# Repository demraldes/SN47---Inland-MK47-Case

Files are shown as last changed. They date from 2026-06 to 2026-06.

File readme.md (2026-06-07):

# Sneed's Inland MK47 Case

The Sneed SN47 is a retro-styled 3D-printed case for the Inland MK47, inspired by vintage Cherry and IBM keyboards. It is directly compatible with the MK47 plate and PCB assembly and reuses the original self-tapping mounting screws.

The latest version of the case adds 2.5 mm of height above the plate. This should better conceal switches and allow the bottom edge of the keycaps to sit more flush to, or slightly below, the top surface. This revision has not been physically tested, so use it at your own risk. No interference or fitment issues are expected.

## Case Files

For best results, the case should be FDM printed as separate top and bottom halves.

[Case files](https://github.com/demraldes/SN47---Inland-MK47-Case/tree/main/case) are located in this repository. A separate collection of [individual parts](https://github.com/demraldes/SN47---Inland-MK47-Case/tree/main/case/separated%20parts) is also included for duo-tone accents or bottom lettering. For these versions, load the components for each half as a single multi-part object.

## Bill of Materials and Assembly
### BOM

| Part | Spec | Qty | Note |
| --- | --- | --- | --- |
| Case screws | M2-0.4x5 mm | 5 | *Flat head recommended. Socket-head screws may clear the PCB, but this has not been tested.* |
| Heat-set inserts | M2x4x3.2 mm | 5 | |
| Case weights (optional) | 1/4 oz low profile | 14 | *16 mm × 19 mm × 3 mm; CK Auto PN# CKsafeAWW005Black01* |
| Plate screws | *See note* | 6 | *Reuse from MK47* |
| Feet/bumpons | 8 mm diameter | 4 | *Self-adhesive cabinet/furniture bumper pads* |

### Assembly

> The plate screws may not feel like they are well-threaded in the mounting bosses. If necessary, a small amount of PTFE tape can help tighten particularly loose screws, though in testing it has not been an issue.

1. Install the M2 heat-set inserts into the pilot holes in the bottom half of the case. The inserts should sit flush with or slightly below the mating surface.

2. If using weights, place them in the rectangular recesses in the bottom half. Adhering them in place is recommended to prevent shifting or rattling during use.
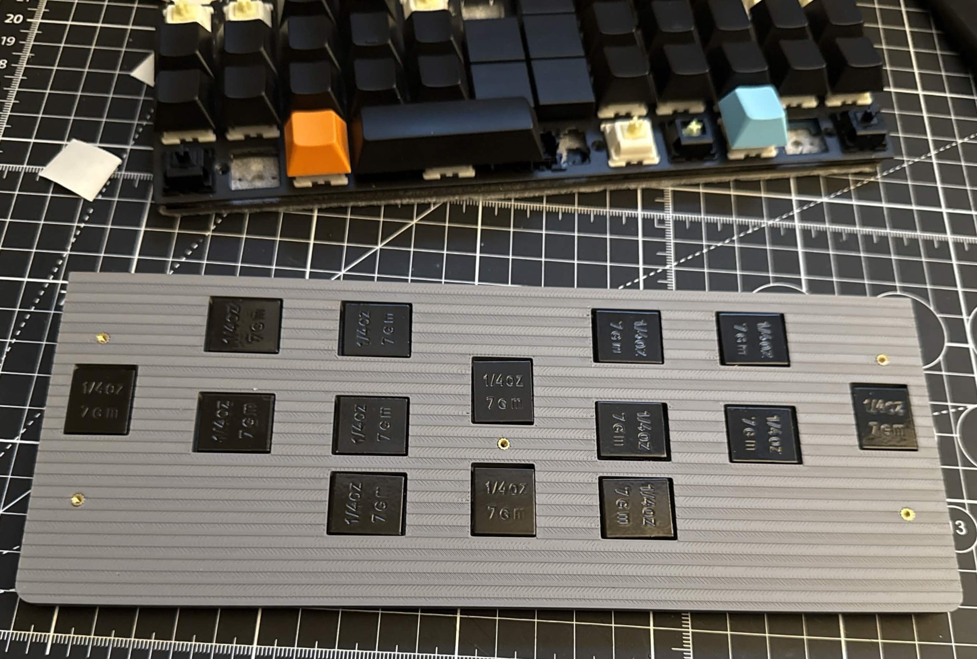
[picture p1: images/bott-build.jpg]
bottom assembly


3. Align the top and bottom halves and loosely install the center M2x5 screw. Install the remaining four screws, then fully tighten all five once they are in place. If using weights, the adhesive pads will need to compress slightly while tightening.
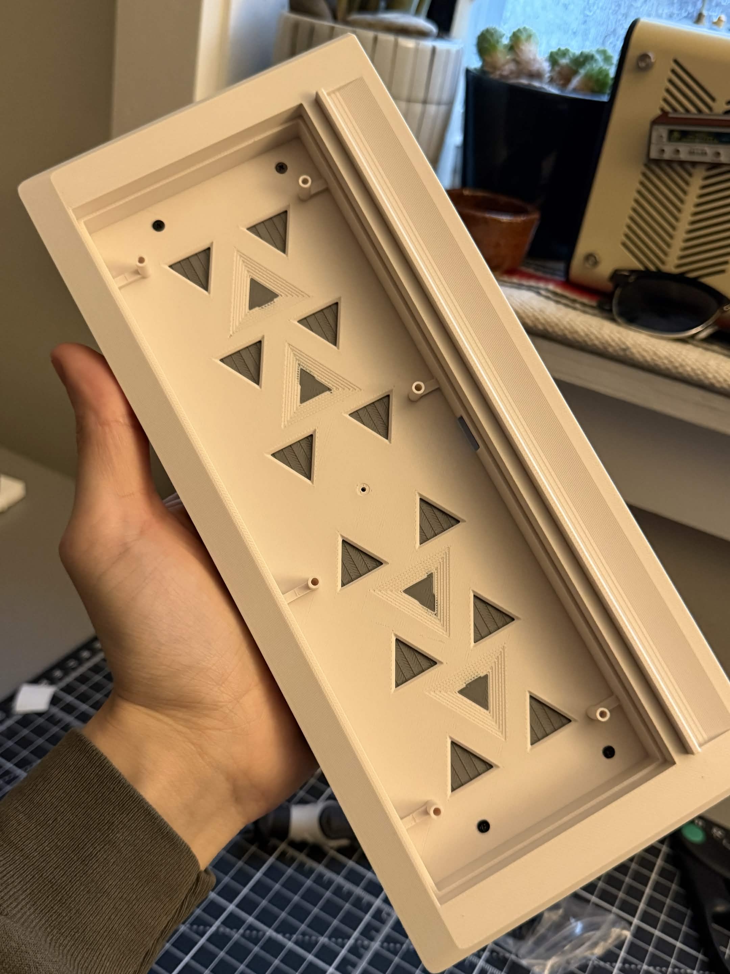
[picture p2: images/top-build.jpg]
top assembly


4. If you have not already done so, remove the plate/PCB assembly from your MK47 and retain the six self-tapping plate screws. Only these six screws need to be removed. Leave the screw securing the PCB to the plate installed and keep the assembly intact.

5. Place the MK47 assembly into the SN47 case. Press it firmly into position until fully seated. Reinstall the six self-tapping plate screws to secure the plate to the case.

## Images
> These images depict the case before adjustments were made to add height above the plate. The current version should sit about flush with to bottom of the keycaps.

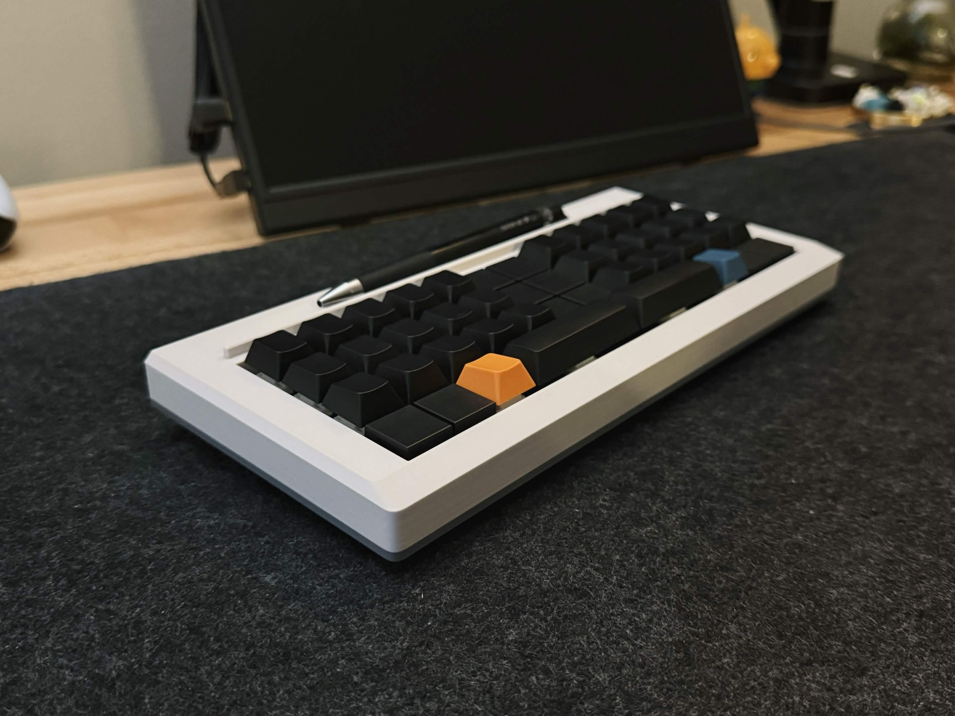
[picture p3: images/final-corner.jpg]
case image

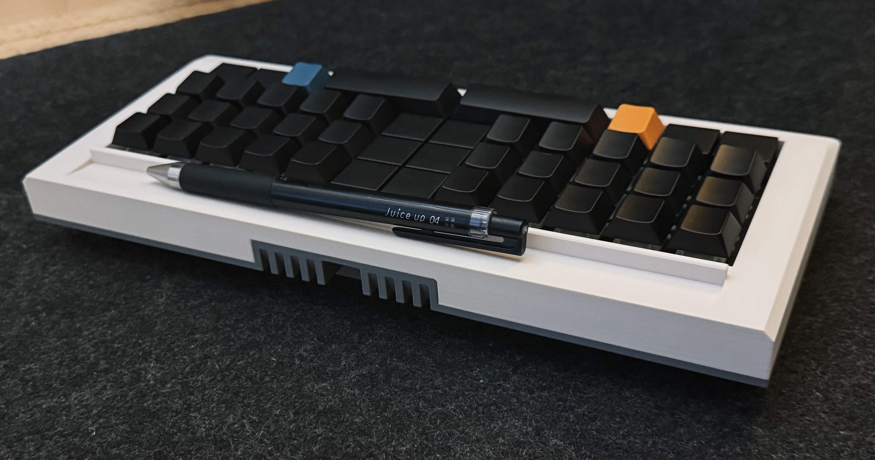
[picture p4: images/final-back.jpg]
case image

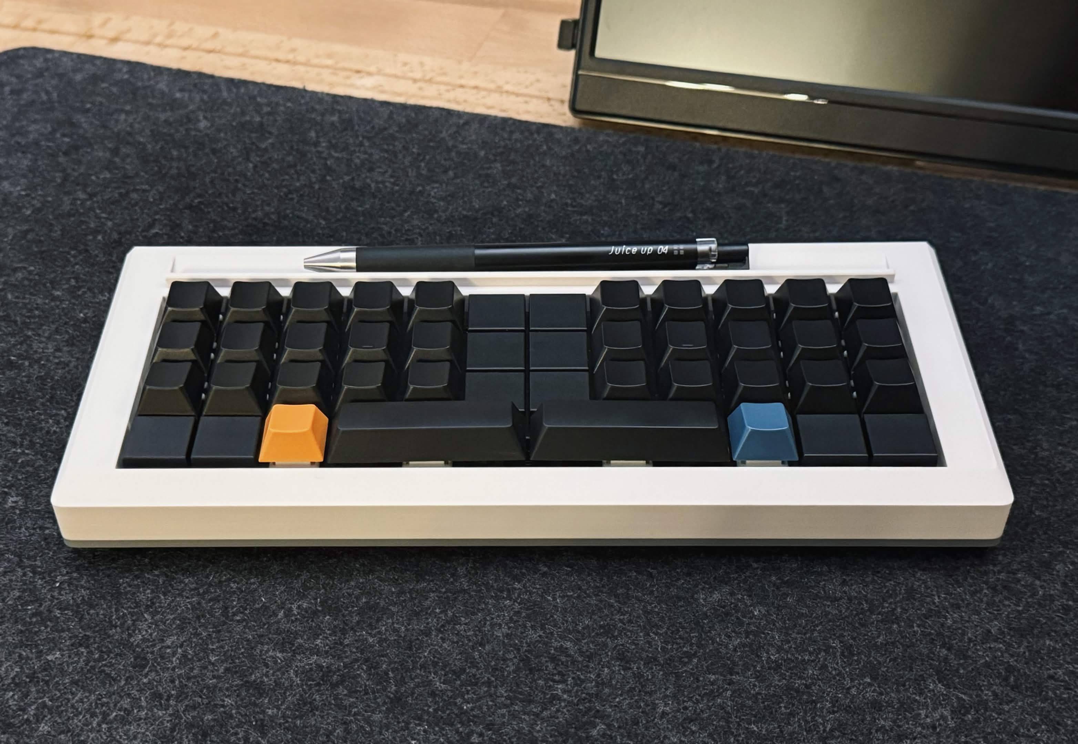
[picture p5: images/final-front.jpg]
case image


## Credits
Valaadus on Discord for inspiring the thermal accent around the USB port and color accents, and for working through printing gremlins.

The 40% Discord community for being an incredible group of helpful people and an invaluable resource in learning to do this design work.

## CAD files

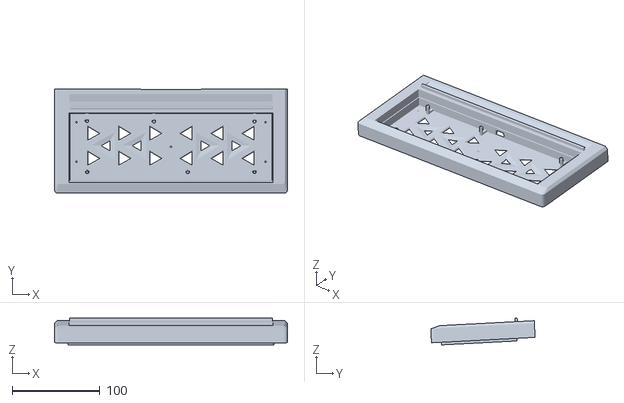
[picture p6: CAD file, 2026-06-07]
case/separated parts/top-main_sn-mk47.stl
265.0 x 118.6 x 30.5

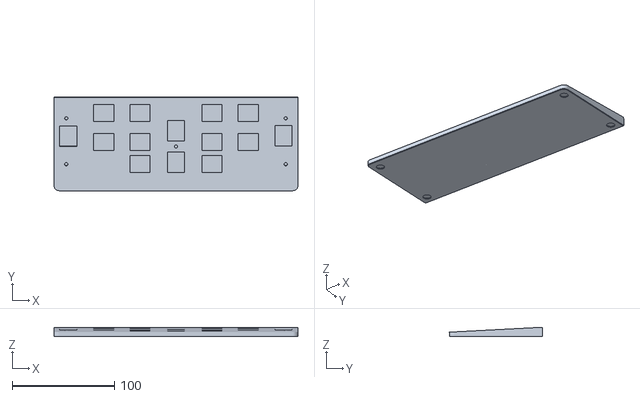
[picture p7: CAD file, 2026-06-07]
case/bott_sn-mk47.stl
239.0 x 91.6 x 9.26

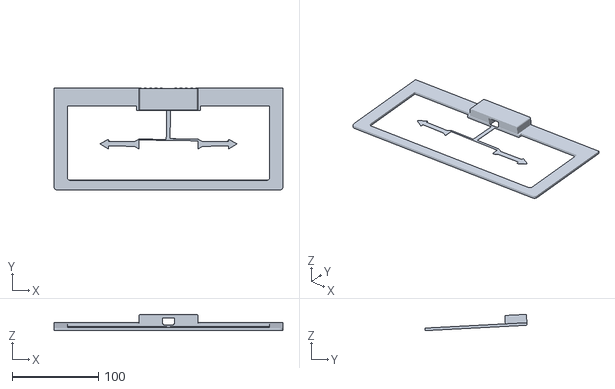
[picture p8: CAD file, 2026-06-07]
case/separated parts/top-accent_sn-mk47.stl
265.0 x 118.1 x 18.9

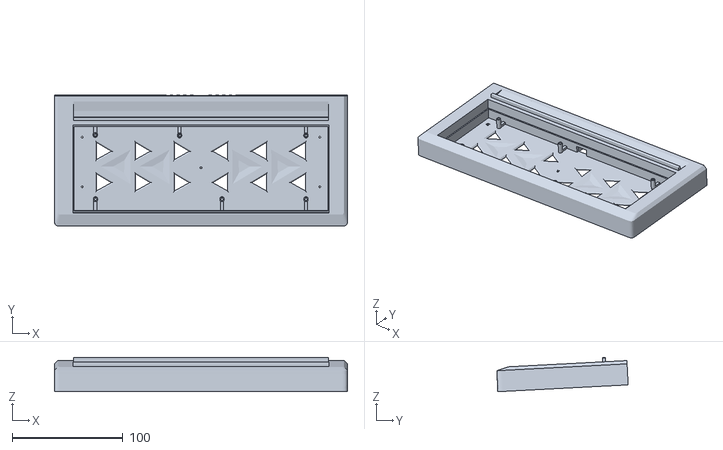
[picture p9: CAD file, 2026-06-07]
case/top_sn-mk47.stl
265.0 x 118.8 x 31.1

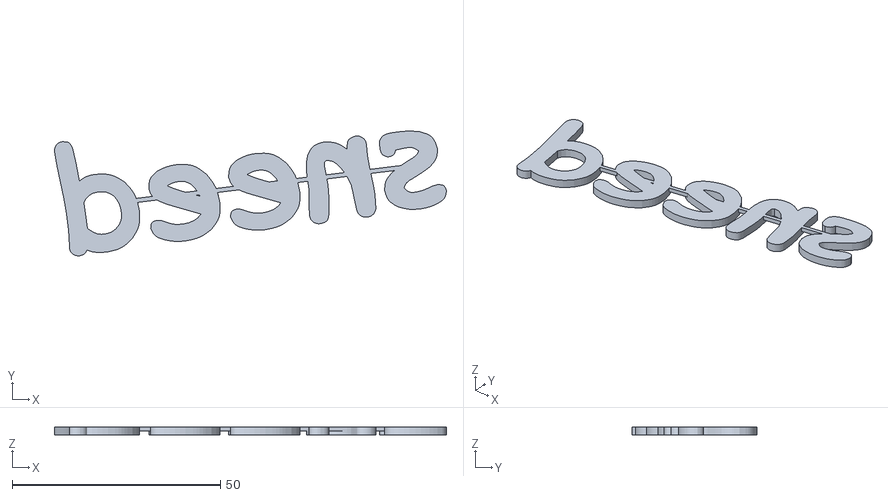
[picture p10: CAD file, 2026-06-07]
case/separated parts/bott-lettering_sn-mk47.stl
94.1 x 29.9 x 2.00

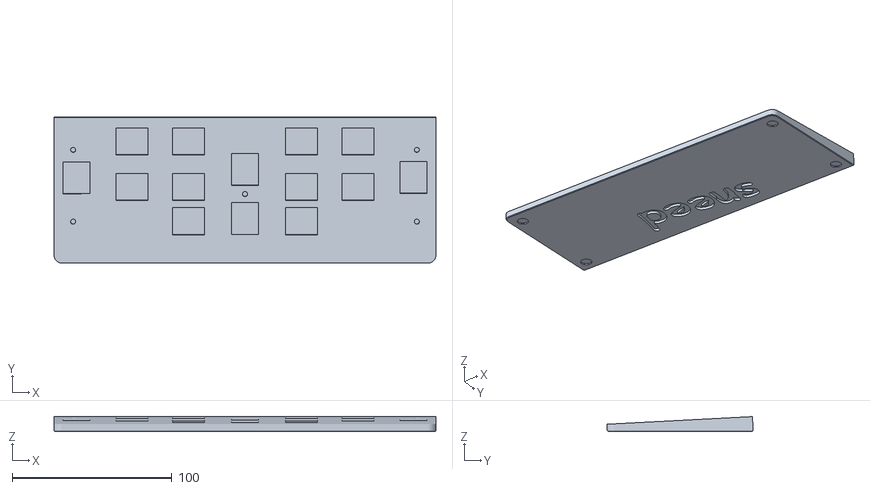
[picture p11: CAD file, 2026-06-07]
case/separated parts/bott_sn-mk47.stl
239.0 x 91.6 x 9.26
